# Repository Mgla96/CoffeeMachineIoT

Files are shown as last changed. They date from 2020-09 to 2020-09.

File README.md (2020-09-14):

# CoffeeMachineIoT

<p align="center">
png
</p>

### About
This is an automated IoT Coffee Machine I built that is controlled by a Raspberry Pi. When it is activated through a Siri Voice command such as "make coffee", it gathers Twitter activity from the past 24 hours from people tagging my account using the hashtags #darkroast, #mediumroast, or #lightroast and makes coffee with the roast of coffee bean that is voted on the most in this time period.
<br>
<br>
Siri is implemented through SiriControl an open source framework created by Sanjeet Chatterjee.

### Hardware

#### Coffee Bean Dispenser
Each servo controls an individual coffee bean dispenser. These coffee bean dispensers are made up of Pringles cans for the top and fruit cans for the bottom. The servo is fixed on the fruit can and rotates the Pringles can. Both the fruit can and Pringles can have holes cut in them so during rotation of the Pringles can, these holes line up and the coffee beans fall out into the coffee machine.

* GPIO-4 controls the servo that dispenses Dark Roast
* GPIO-5 controls the servo that dispenses Medium Roast
* GPIO-17 controls the servo that dispenses Light Roast
<p align="center">
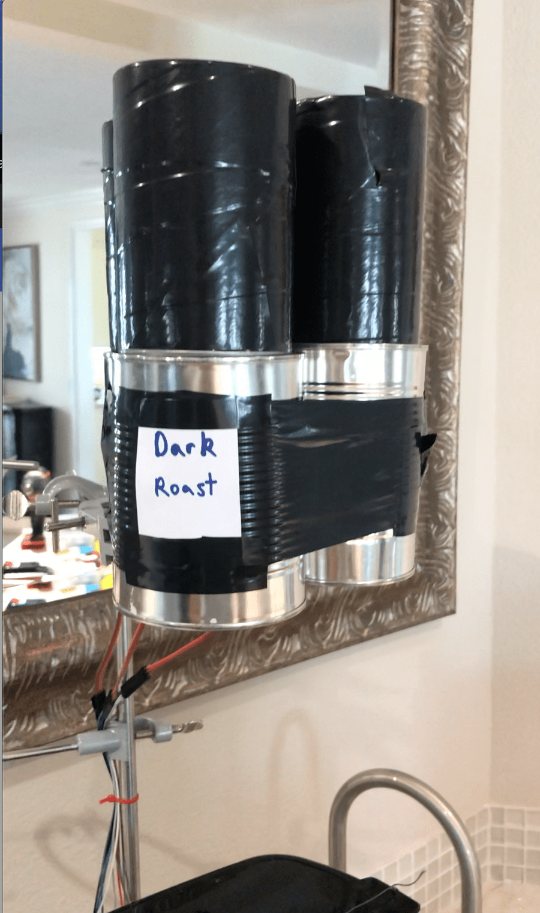
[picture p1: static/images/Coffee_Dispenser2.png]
png

</p>

#### Lid Closer

* GPIO-18 controls the servo that closes the Coffee Machine Lid
<p align="center">
png
</p>

#### Start Button Presser

* GPIO-8 controls the servo that starts the Coffee Machine Brewing
<p align="center">
png
</p>

#### OLED Screen

* A 0.96 Inch OLED screen acts as the display that shows which coffee bean was chosen and how many votes that bean had.
<p align="center">
png
</p>

#### 3D-Printed Parts

* OLED Screen — [Thingiverse STL Link](https://www.thingiverse.com/thing:2176764) 
* Custom Servo Mount — See stls Folder
* Custom Servo Closing Lever — See stls Folder

#### Raspberry Pi & Wiring

* Raspberry Pi 3B+
* Breadboard
* Jumper Cables
* Resistors 
* 8-channel Relay

<p align="center">
png
</p>

The breadboard has a separate power supply which powers the servos and oled display. The servos signal wire is placed in the breadboard where it connected to a resistor and to it's respective GPIO pin on the Raspberry Pi.
<p align="center">
png
</p>
<p align="center">
png
</p>
<br>
<br>
The 8-channel Relay was used for a previous iteration but it could still be used to plug the drip coffee machine into and an extra member function for the BrewCoffee class which turns the machine on before brewing and off when it is not in use to save power.

### Software
The main files are
* **coffeecontrol.py** — This holds the BrewCoffee class that handles all the logic of the coffee machine
* **twitter.py** — Controls the Twitter Voting System
* **siricontrol.py** — Allowing Siri voice commands using Sanjeet Chatterjee's open source code
* **modules/coffeeModule.py** — The module for the siricontrol which triggers the coffee machine with the words "make coffee"

### Demonstration Video
#### Coffee Beans Pouring
<p align="center">
gif
</p>

#### Lid Closing And Brew Starting
<p align="center">
gif
</p>

#### OLED Screen Display
<p align="center">
gif
</p>

#### Closer Look At Start Button Servo
<p align="center">
gif
</p>

#### Coffee Good To Go
<p align="center">
gif
</p>

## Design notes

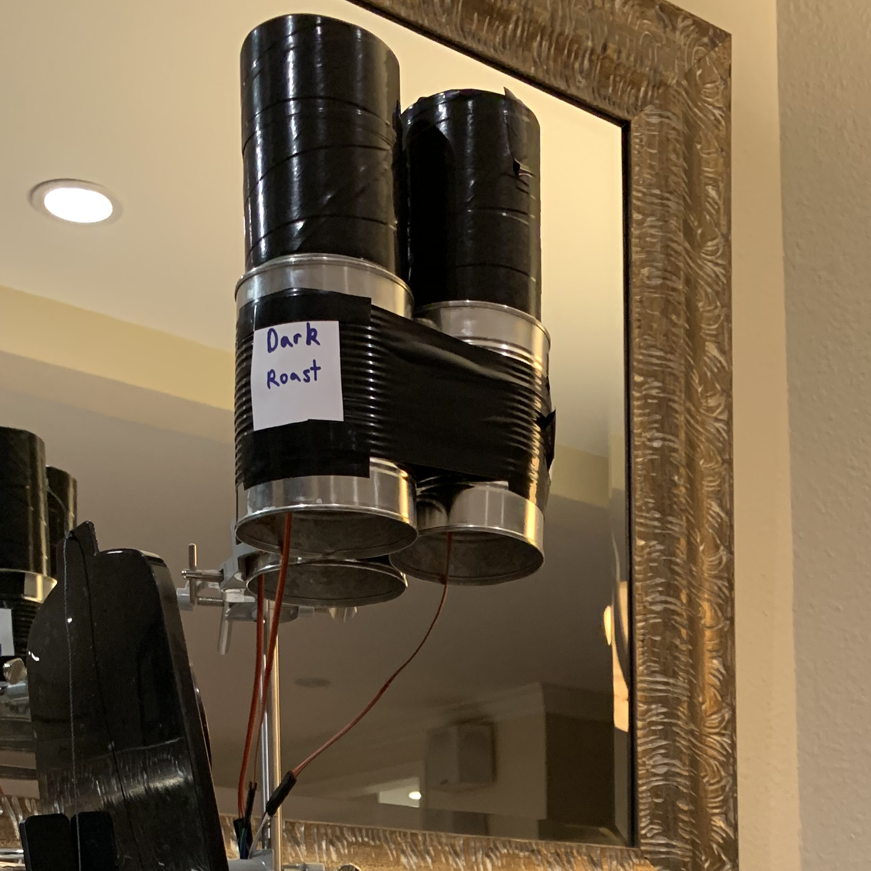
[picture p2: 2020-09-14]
static/images/Coffee_Dispenser.png

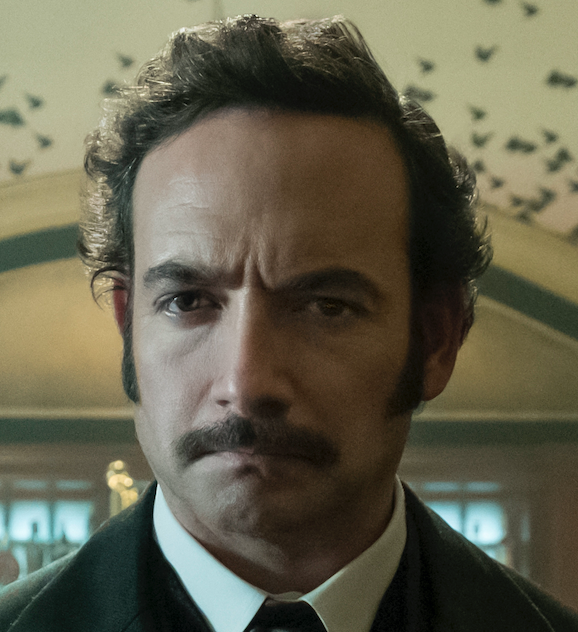
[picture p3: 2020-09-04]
static/images/Poe.jpg

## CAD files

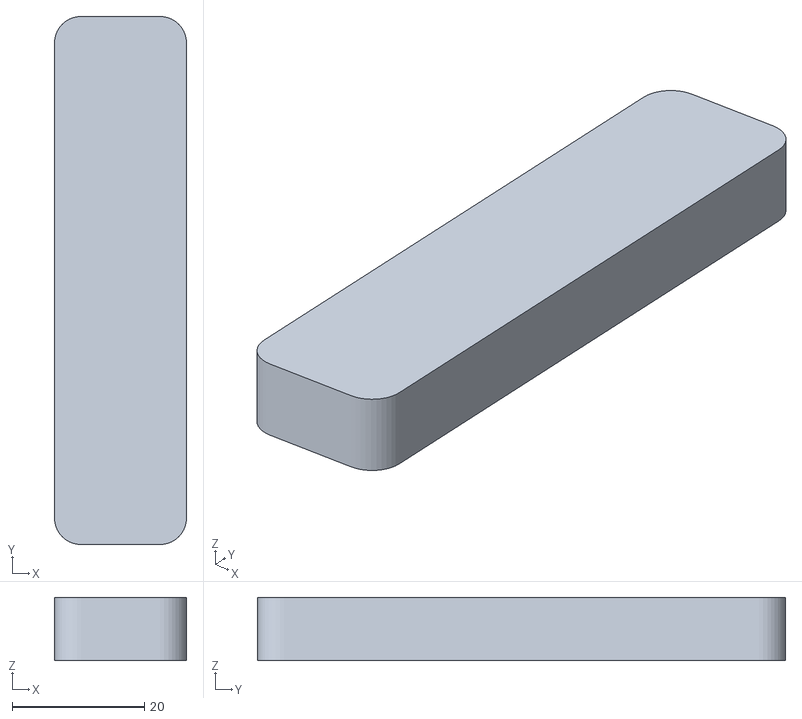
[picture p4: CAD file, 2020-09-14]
static/stls/Lever_v1.stl
20.0 x 80.0 x 9.60

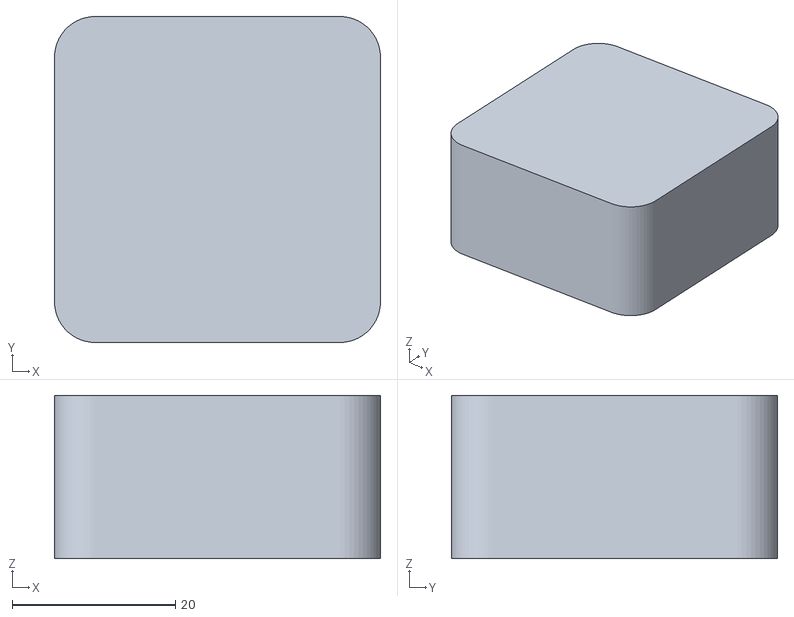
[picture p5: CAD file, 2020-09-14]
static/stls/ServoMount_v1.stl
40.0 x 40.0 x 20.0

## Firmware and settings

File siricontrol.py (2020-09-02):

import time
import imaplib
import email
import os
import pkgutil
from dotenv import load_dotenv


class ControlException(Exception):
    pass


class Control():
    def __init__(self, username, password):
        print("------------------------------------------------------")
        print("-                    SIRI CONTROL                    -")
        print("-          Based Off Of Sanjeet Chatterjee's Code    -")
        print("-      Website: https://medium.com/@thesanjeetc      -")
        print("------------------------------------------------------")

        try:
            self.last_checked = -1
            self.mail = imaplib.IMAP4_SSL("imap.gmail.com", 993)
            self.mail.login(username, password)
            self.mail.list()
            self.mail.select("Notes")

            # Gets last Note id to stop last command from executing
            result, uidlist = self.mail.search(None, "ALL")
            try:
                self.last_checked = uidlist[0].split()[-1]
            except IndexError:
                pass

            self.load()
            self.handle()
        except imaplib.IMAP4.error:
            print("Your username and password is incorrect")
            print("Or IMAP is not enabled.")

    def load(self):
        """Try to load all modules found in the modules folder"""
        print("\n")
        print("Loading modules...")
        self.modules = []
        path = os.path.join(os.path.dirname(__file__), "modules")
        directory = pkgutil.iter_modules(path=[path])
        for finder, name, ispkg in directory:
            try:
                loader = finder.find_module(name)
                module = loader.load_module(name)
                if hasattr(module, "commandWords") \
                        and hasattr(module, "moduleName") \
                        and hasattr(module, "execute"):
                    self.modules.append(module)
                    print("The module '{0}' has been loaded, "
                          "successfully.".format(name))
                else:
                    print("[ERROR] The module '{0}' is not in the "
                          "correct format.".format(name))
            except:
                print("[ERROR] The module '" + name + "' has some errors.")
        print("\n")

    def fetch_command(self):
        """Retrieve the last Note created if new id found"""
        self.mail.list()
        self.mail.select("Notes")

        result, uidlist = self.mail.search(None, "ALL")
        try:
            latest_email_id = uidlist[0].split()[-1]
        except IndexError:
            return

        if latest_email_id == self.last_checked:
            return

        self.last_checked = latest_email_id
        result, data = self.mail.fetch(latest_email_id, "(RFC822)")
        voice_command = email.message_from_string(data[0][1].decode('utf-8'))
        return str(voice_command.get_payload()).lower().strip()

    def handle(self):
        """Handle new commands
        Poll continuously every second and check for new commands.
        """
        print("Fetching commands...")
        print("\n")

        while True:
            try:
                command = self.fetch_command()
                if not command:
                    raise ControlException("No command found.")

                print("The word(s) '" + command + "' have been said")
                for module in self.modules:
                    foundWords = []
                    for word in module.commandWords:
                        if str(word) in command:
                            foundWords.append(str(word))
                    if len(foundWords) == len(module.commandWords):
                        try:
                            module.execute(command)
                            print("The module {0} has been executed "
                                  "successfully.".format(module.moduleName))
                        except:
                            print("[ERROR] There has been an error "
                                  "when running the {0} module".format(
                                      module.moduleName))
                    else:
                        print("\n")
            except (TypeError, ControlException):
                pass
            except Exception as exc:
                print("Received an exception while running: {exc}".format(
                    **locals()))
                print("Restarting...")
            time.sleep(1)


if __name__ == '__main__':
    load_dotenv()
    username = os.environ.get("username")
    password = os.environ.get("password")
    Control(username, password)

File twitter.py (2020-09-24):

import tweepy
import os 
from dotenv import load_dotenv
import time
import datetime
load_dotenv()

class Twitter():
    def __init__(self):
        auth=tweepy.OAuthHandler(os.environ.get("api_consumer_key"),os.environ.get("api_consumer_key_secret"))
        auth.set_access_token(os.environ.get("api_access_token"),os.environ.get("api_access_token_secret"))
        self.api=tweepy.API(auth)
    def getVote(self):
        mentions = self.api.mentions_timeline()
        choice={}
        mx=["",0]
        current_utc = datetime.datetime.utcnow()
        for mention in mentions:
            date = mention.created_at
            dif = current_utc-date
            time_delta=datetime.timedelta(days=1)
            if dif < time_delta:
                text = mention.text.split()
                for word in text:
                    if word[0]=="#":
                        typ = word[1:]
                        if typ in choice:
                            choice[typ]+=1
                        else:
                            choice[typ]=1
                        if choice[typ]>mx[1]:
                            mx[1]=choice[typ]
                            mx[0]=typ
        if mx[0]!="":
            print("people have chosen",mx[0], "as the coffee to make this morning. Starting Brew! Beep Boop")
            return (mx[0],mx[1])
        else:
            print("nobody voted :(")
            return (mx[0],mx[1])

if __name__=="__main__":
    twit=Twitter()
    coffee_choice,amount_votes=twit.getVote()
    print(coffee_choice,amount_votes)

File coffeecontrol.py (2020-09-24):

#!/usr/bin/python3
import RPi.GPIO as GPIO
import time
import busio
from board import SCL, SDA
import busio
import adafruit_ssd1306
import digitalio
from PIL import Image, ImageDraw, ImageFont

class BrewCoffee():
    def __init__(self, coffeechoice):
        self.coffeechoice=coffeechoice.lower()
        GPIO.setmode(GPIO.BCM) 
        #Dark Roast - Servo Setup
        GPIO.setup(4,GPIO.OUT) 
        self.servo1 = GPIO.PWM(4,50) # Note 4 is pin, 50 = 50Hz pulse    
        self.servo1.start(0)
        #Medium Roast
        GPIO.setup(5,GPIO.OUT)
        self.servo2 = GPIO.PWM(5,50) 
        self.servo2.start(0)
        #Light Roast
        GPIO.setup(17,GPIO.OUT)
        self.servo3 = GPIO.PWM(17,50) 
        self.servo3.start(0)
        #Close Top
        GPIO.setup(18,GPIO.OUT)
        self.close_top_servo = GPIO.PWM(18,50) 
        self.close_top_servo.start(0)
        #Brew Starter
        GPIO.setup(8,GPIO.OUT)
        self.start_brew_servo = GPIO.PWM(8,50)
        self.start_brew_servo.start(0)
    
    def setAngle(self,angle,pwm):
            duty = angle / 18 + 2
            GPIO.output(5, True)
            pwm.ChangeDutyCycle(duty)
            time.sleep(1)
            GPIO.output(5, False)
            pwm.ChangeDutyCycle(0)

    def startBrew(self):
        '''
        Starts brewing coffee
        '''
        print("starting brew")
        def start(pwm):
            self.setAngle(180,pwm)
            time.sleep(2)
            self.setAngle(0,pwm)
        try:
            start(self.start_brew_servo)
            self.start_brew_servo.stop()
        except:
            GPIO.cleanup()

    def closeTop(self):
        '''
        Closes Top of Coffee Machine
        '''
        def close(pwm):
            self.setAngle(0,pwm)
            self.setAngle(90,pwm)
        try:
            close(self.close_top_servo)
            self.close_top_servo.stop()
        except:
            GPIO.cleanup()

    def pourBean(self):
        '''
        Pours the coffee bean that was selected into French Press
        '''
        def pour(pwm):
            for _ in range(10):
                self.setAngle(0,pwm)
                self.setAngle(180,pwm)
            self.setAngle(0,pwm)
        print(self.coffeechoice,"was chosen. Pouring the beans")
        if self.coffeechoice=="darkroast":
            pour(self.servo1)
        elif self.coffeechoice=="mediumroast":
            print("medium roast")
            pour(self.servo2)
        elif self.coffeechoice=="lightroast":
            print("dark roast")
            pour(self.servo3)
        else:
            print(self.coffeechoice,"is not one of the 3 choices so defaulting to medium")
            self.coffeechoice="mediumroast"
            pour(self.servo2)

    def displayCoffeeChoice(self, coffee_choice,amount_votes):
        '''
        Shows on OLED Screen the coffee choice that was chosen through Twitter
        '''
        print(amount_votes)
        i2c = busio.I2C(SCL, SDA)
        display = adafruit_ssd1306.SSD1306_I2C(128, 32, i2c)
        display.fill(0)
        display.show()
        image = Image.new("1", (display.width, display.height))
        draw = ImageDraw.Draw(image)
        font = ImageFont.truetype("/usr/share/fonts/truetype/dejavu/DejaVuSans.ttf", 11)
        font2 = ImageFont.truetype("/usr/share/fonts/truetype/dejavu/DejaVuSans.ttf", 14)
        draw.text((0, -3), "Twitter Voted For", font=font, fill=255)
        draw.text((0, 8), coffee_choice, font=font2, fill=255)
        draw.text((0, 20), "# votes: "+str(amount_votes), font=font, fill=255)
        display.image(image)
        display.show()
        
    def clearCoffeeChoice(self):
        '''
        Clears the Coffee Choice on the OLED Screen
        '''
        i2c = busio.I2C(SCL, SDA)
        display = adafruit_ssd1306.SSD1306_I2C(128, 32, i2c)
        display.fill(0)
        display.show()

    def displayFace(self):
        '''
        Displays a face on the OLED Screen for fun
        '''
        i2c = busio.I2C(SCL, SDA)
        display = adafruit_ssd1306.SSD1306_I2C(128, 32, i2c)
        display.fill(0)
        display.show()
        image = (Image.open('static/images/Poe.jpg').resize((display.width, display.height), Image.BICUBIC).convert("1"))
        display.image(image)
        display.show()


        

        


    
            

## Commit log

2020-08-23 servos and relays
2020-08-31 current coffee controls work
2020-09-12 fixing timedelta for twitter
    [twitter.py]
2020-09-13 working motors
